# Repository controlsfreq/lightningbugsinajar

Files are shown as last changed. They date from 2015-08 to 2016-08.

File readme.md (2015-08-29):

# Readme #

The Lightning Bugs in a Jar (LBJ) application is used to control up to 8 LEDs and flash them randomly as if they were lightning bugs.

## Toolchain ##

* [WinAVR](http://sourceforge.net/projects/winavr/files/) - Compiler, linker, archiver, etc.
* [AvrDude](http://www.nongnu.org/avrdude/) - Programmer interface application.
* [LibUSB](http://sourceforge.net/projects/libusb-win32/) - USB driver for AvrDude which allows it to interface with the AVRISP mkII. Running `bin/inf-wizard.exe` will create a driver for a connected AVRISP mkII and install it.
* [Cygwin](https://www.cygwin.com) - Provides Make and a build environment.

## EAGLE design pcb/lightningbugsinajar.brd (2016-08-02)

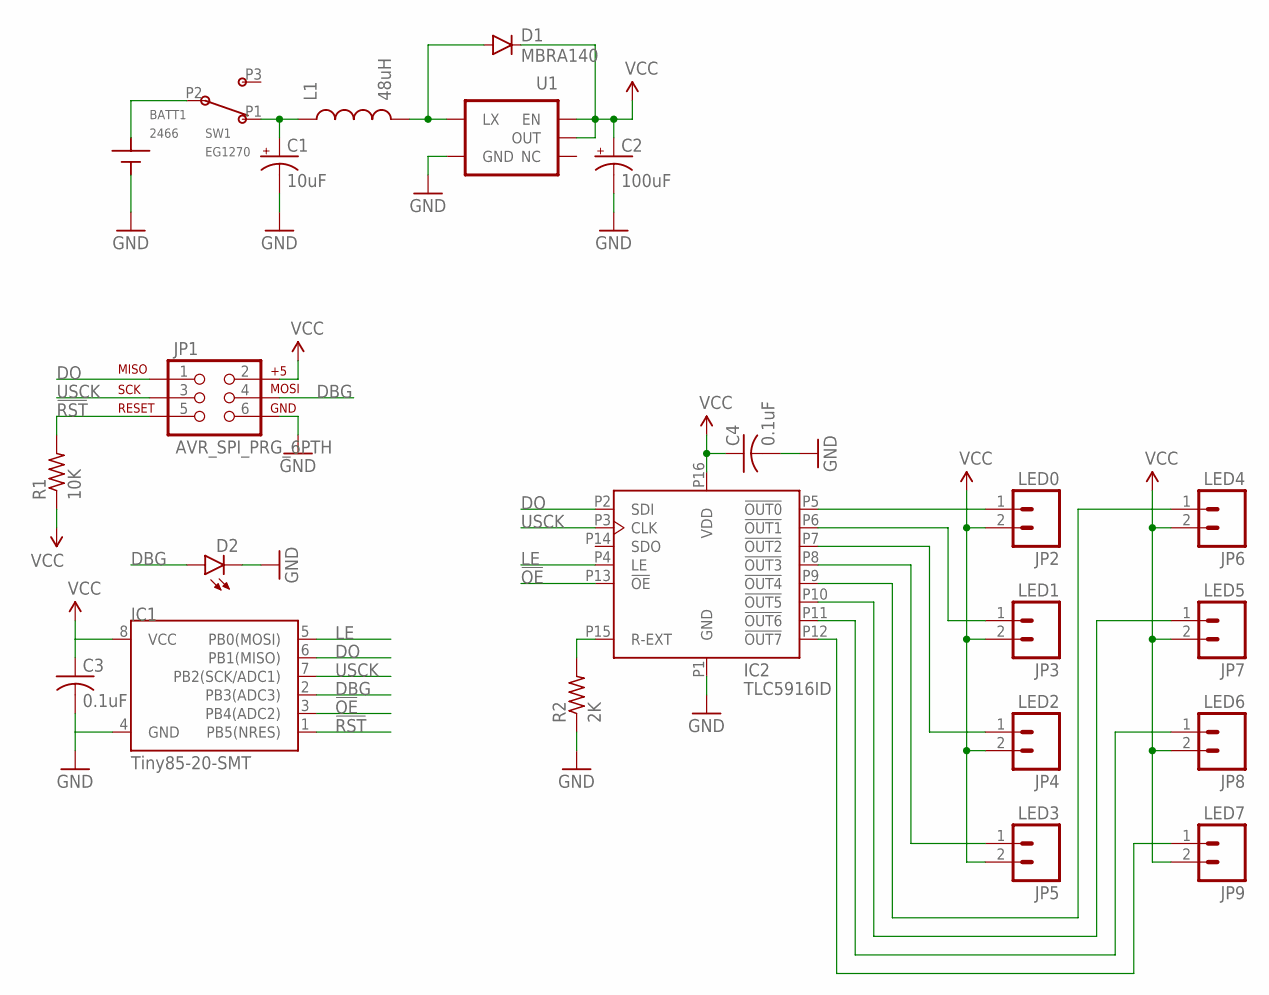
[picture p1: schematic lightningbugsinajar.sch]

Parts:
BATT1: 2466
C1: 10uF; EIA3528
C2: 100uF; EIA3528
C3, C4: 0.1uF; C0805
D1: MBRA140; SMA-DIODE
D2: LED3MM
IC1: Tiny85-20-SMT; SO08-EIAJ
IC2: TLC5916ID; SOIC-16
JP1: AVR_SPI_PRG_6PTH; 2X3
JP2: LED0; 1X02
JP3: LED1; 1X02
JP4: LED2; 1X02
JP5: LED3; 1X02
JP6: LED4; 1X02
JP7: LED5; 1X02
JP8: LED6; 1X02
JP9: LED7; 1X02
L1: 48uH; CR54
R1: 10K; R0805
R2: 2K; R0805
SW1: EG1270
U1: V_REG_NCP1400SOT23-5; SOT23-5

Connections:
3: SW1.P3 (3)
!OE: IC1.3 (PB4(ADC2)), IC2.P13 (!OE)
!RST: IC1.1 (PB5(NRES)), JP1.5, R1.2
DBG: D2.A, IC1.2 (PB3(ADC3)), JP1.4
DO: IC1.6 (PB1(MISO)), IC2.P2 (SDI), JP1.1
GND: BATT1.NEG, C1.C (-), C2.C (-), C3.2, C4.2, D2.K (C), IC1.4 (GND), IC2.P1 (GND), JP1.6, R2.1, U1.4 (GND)
LE: IC1.5 (PB0(MOSI)), IC2.P4 (LE)
unnamed: C1.A (+), L1.P$1 (1), SW1.P1 (1)
unnamed: D1.A, L1.P$2 (2), U1.5 (LX)
unnamed: IC2.P5 (!OUT0), JP2.1
unnamed: IC2.P15 (R-EXT), R2.2
unnamed: IC2.P6 (!OUT1), JP3.1
unnamed: IC2.P7 (!OUT2), JP4.1
unnamed: IC2.P8 (!OUT3), JP5.1
unnamed: IC2.P9 (!OUT4), JP6.1
unnamed: IC2.P10 (!OUT5), JP7.1
unnamed: BATT1.POS, SW1.P2 (COM)
unnamed: IC2.P11 (!OUT6), JP8.1
unnamed: IC2.P12 (!OUT7), JP9.1
USCK: IC1.7 (PB2(SCK/ADC1)), IC2.P3 (CLK), JP1.3
VCC: C2.A (+), C3.1, C4.1, D1.C, IC1.8 (VCC), IC2.P16 (VDD), JP1.2, JP2.2, JP3.2, JP4.2, JP5.2, JP6.2, JP7.2, JP8.2, JP9.2, R1.1, U1.1 (EN), U1.2 (OUT)

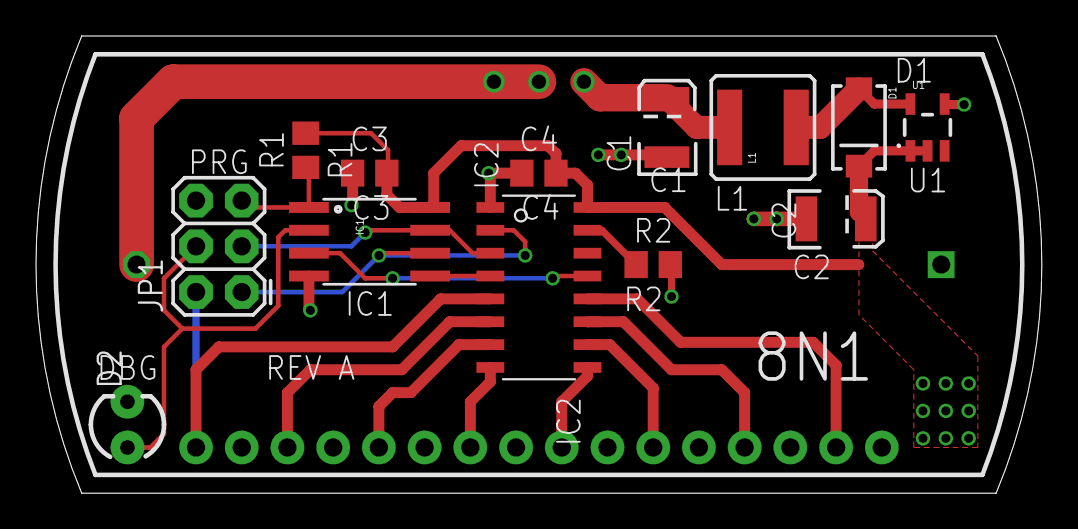
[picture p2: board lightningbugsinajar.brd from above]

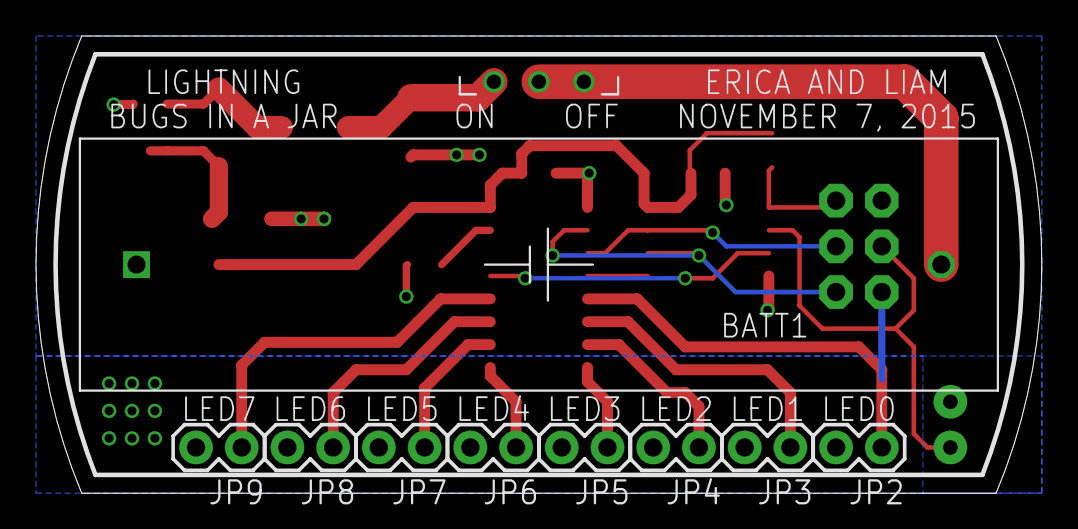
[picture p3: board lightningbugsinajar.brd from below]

Board: 2 copper layers, 55.9 x 25.4 mm, 23 parts (10 on the bottom side), 20 nets.

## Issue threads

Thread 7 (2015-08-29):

Create TLC591x driver

controlsfreq, 2015-08-29:
Create a TLC591x driver which allows control of an individual LED or all 8 at once. No error detection necessary, no special mode necessary, output enable should be made optional.

Closed 2015-08-30.

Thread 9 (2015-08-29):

Create a basic SPI driver

controlsfreq, 2015-08-29:
Create a basic SPI driver which allows setting baud rate (some set values) and reading and writing from/to the bus. Also, allows manual control of CS pin.

Closed 2015-08-30.

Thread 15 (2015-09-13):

Create AVR Timer1 driver

controlsfreq, 2015-09-13:
Create a timer1 driver for the AVR attiny. Timer must support interrupting at specified intervals.

Closed 2015-09-17.

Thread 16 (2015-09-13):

Add ISR for Timer1 which increments soft-PWM counter

controlsfreq, 2015-09-13:
Add an application level ISR which increments the soft-PWM counter.

controlsfreq, 2015-09-17:
This is already included in #17. No need to have a separate task for it.

Closed 2015-09-17.

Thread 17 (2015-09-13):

Write application layer soft-PWM module

controlsfreq, 2015-09-13:
Write a software PWM module at the application layer. This module must use the Timer1 driver to interrupt at a set time period and use a software counter to determine the correct output level of a single channel. This module must update the TLC5916 driver with the currently set PWM value whenever the channel value is changed (may be updated at each time step if necessary).

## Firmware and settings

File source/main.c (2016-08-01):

/**
 * @file   main.c
 * @brief  This file contains the main entry point to the LED Bugs In A Jar application.
 * @author Liam Bucci <liam.bucci@gmail.com>
 * @date   2015-08-23
 * @copyright
 * {
 *     Copyright 2015 Liam Bucci
 *
 *     Licensed under the Apache License, Version 2.0 (the "License");
 *     you may not use this file except in compliance with the License.
 *     You may obtain a copy of the License at
 *
 *         http://www.apache.org/licenses/LICENSE-2.0
 *
 *     Unless required by applicable law or agreed to in writing, software
 *     distributed under the License is distributed on an "AS IS" BASIS,
 *     WITHOUT WARRANTIES OR CONDITIONS OF ANY KIND, either express or implied.
 *     See the License for the specific language governing permissions and
 *     limitations under the License.
 * }
 */

#define F_CPU 1000000UL

#include <avr/io.h>
#include <avr/interrupt.h>
#include <util/delay.h>

#include "pin.h"
#include "spi.h"
#include "tlc591x.h"
#include "controller.h"
#include "timer.h"

volatile uint8_t g_timer_counter = 0;

pin_t debug_pin = {
    PIN_BANK_B,
    PIN_NUM_3,
    false
};

int main( int argc, char *argv[] )
{
	//char major_version = LBJ_MAJOR_VERSION;
	//char minor_version = LBJ_MINOR_VERSION;
	//char patch_version = LBJ_PATCH_VERSION;

    timer_t timer1 = {
        TIMER_NUM_1,
        TIMER_PRE_8,
        true
    };

    spi_t spi = {
        SPI_BAUD_1M,
        {
            PIN_BANK_B,
            PIN_NUM_3,
            true
        }, // SPI CS
        {
            PIN_BANK_B,
            PIN_NUM_1,
            false
        }, // SPI MOSI
        {
            PIN_BANK_B,
            PIN_NUM_0,
            false
        }, // SPI MISO
        {
            PIN_BANK_B,
            PIN_NUM_2,
            false
        } // SPI SCLK
    };

    tlc591x_t tlc = {
        spi,
        { PIN_BANK_B, PIN_NUM_0, true },
        { PIN_BANK_B, PIN_NUM_4, false }
    };

    (void)timer_init( &timer1 );
    (void)timer_set_compare( &timer1, 125 );
    (void)tlc591x_init( &tlc );
    (void)tlc591x_enable_output( &tlc );

    sei();

    (void)timer_enable_int( &timer1 );
    (void)timer_start( &timer1 );

    (void)controller_init( &tlc );
    (void)controller_loop();

	return 0;
}



ISR(INT0_vect)
{
    (void)pin_assert( &debug_pin );
    while(1); /* Trap */
}

ISR(PCINT0_vect)
{
    (void)pin_assert( &debug_pin );
    while(1); /* Trap */
}

ISR(TIM1_OVF_vect)
{
    (void)pin_assert( &debug_pin );
    while(1); /* Trap */
}

ISR(TIM0_OVF_vect)
{
    (void)pin_assert( &debug_pin );
    while(1); /* Trap */
}

ISR(EE_RDY_vect)
{
    (void)pin_assert( &debug_pin );
    while(1); /* Trap */
}

ISR(ANA_COMP_vect)
{
    (void)pin_assert( &debug_pin );
    while(1); /* Trap */
}

ISR(ADC_vect)
{
    (void)pin_assert( &debug_pin );
    while(1); /* Trap */
}

ISR(TIM1_COMPB_vect)
{
    (void)pin_assert( &debug_pin );
    while(1); /* Trap */
}

ISR(TIM0_COMPA_vect)
{
    (void)pin_assert( &debug_pin );
    while(1); /* Trap */
}

ISR(TIM0_COMPB_vect)
{
    (void)pin_assert( &debug_pin );
    while(1); /* Trap */
}

ISR(WDT_vect)
{
    (void)pin_assert( &debug_pin );
    while(1); /* Trap */
}

ISR(USI_START_vect)
{
    (void)pin_assert( &debug_pin );
    while(1); /* Trap */
}

ISR(USI_OVF_vect)
{
    (void)pin_assert( &debug_pin );
    while(1); /* Trap */
}

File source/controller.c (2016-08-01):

/**
 * @file   controller.c
 * @brief  This file contains the controller for 2, 4, or 8 LEDs.
 * @author Liam Bucci <liam.bucci@gmail.com>
 * @date   2015-08-23
 * @copyright
 * {
 *     Copyright 2015 Liam Bucci
 *
 *     Licensed under the Apache License, Version 2.0 (the "License");
 *     you may not use this file except in compliance with the License.
 *     You may obtain a copy of the License at
 *
 *         http://www.apache.org/licenses/LICENSE-2.0
 *
 *     Unless required by applicable law or agreed to in writing, software
 *     distributed under the License is distributed on an "AS IS" BASIS,
 *     WITHOUT WARRANTIES OR CONDITIONS OF ANY KIND, either express or implied.
 *     See the License for the specific language governing permissions and
 *     limitations under the License.
 * }
 */

#include <avr/io.h>
#include <avr/interrupt.h>
#include "tlc591x.h"
#include "pin.h"
#include "ufprng.h"
#include "controller.h"

#define PWM_CHANNELS     8U
#define PWM_RESOLUTION   128U    ///< Must be a power of 2
#define WAVEFORM_UPDATE_COUNT 2U ///< Must be a power of 2
#define WAVEFORM_LENGTH  64U     ///< Must be a power of 2
#define WAVEFORM_ACTIVE_MASK 0x1FU
#define PRNG_UPDATE_COUNT 64U    ///< Must be a power of 2

#ifndef PRNG_SEED
#define PRNG_SEED 1
#endif

/*
 * Use a software counter to implement PWM. Every Timer1 overflow the PWM counter will increment
 * and the controller_loop will update the output values of all PWM channels according to their
 * current duty cycle values.
 *
 * The duty cycle values are taken from the waveform values. The current index of the waveform is
 * stored in g_waveform_index for each LED channel. The waveform index for each channel is only
 * incremented passed zero if the channel is marked active in g_waveform_active. When a channel is
 * marked active it increments it's waveform index every WAVEFORM_UPDATE_COUNT PWM periods.
 *
 * PWM bit = 125us
 * PWM period = 128 * 125us = 16ms
 * Waveform update = 2 * 16ms = 32ms
 * Waveform rollover = 64 * 32ms = 2.048s
 */
static volatile uint8_t g_pwm_dutycycle_counter = 0;
static volatile bool g_pwm_update_flag = false;
static volatile uint8_t g_waveform_update_counter = 0;
static volatile uint8_t g_waveform_index[PWM_CHANNELS] = { 0 };
static volatile bool g_waveform_active[PWM_CHANNELS] = { false, false, false, false, false, false, false, false };
static const uint8_t WAVEFORM_VALUES[WAVEFORM_LENGTH] = {   0,   2,   4,   8,  14,  22,  30,  40,
                                                           50,  60,  72,  82,  94, 102, 110, 118,
                                                          122, 126, 128, 126, 126, 122, 118, 114,
                                                          108, 102,  96,  88,  82,  74,  68,  60,
                                                           54,  48,  42,  38,  34,  28,  26,  22,
                                                           18,  16,  14,  12,  10,   8,   6,   5,
                                                            4,   3,   2,   2,   1,   0,   0,   0,
                                                            0,   0,   0,   0,   0,   0,   0,   0 };
static uint8_t g_prng_update_counter = 0;
static uint8_t g_output_value = 0x00U;
static tlc591x_t * g_ptlc;
static bool g_run = true;
static ufprng_t g_prng;

pin_t debug_pin_test = {
    PIN_BANK_B,
    PIN_NUM_3,
    false
};

bool controller_init( tlc591x_t * const tlc )
{
    g_ptlc = tlc;

    // Seed prng
    ufprng_seed( &g_prng, PRNG_SEED );

    return true;
}

bool controller_loop( void )
{
    bool error_code = false;
    uint8_t local_pwm_dutycycle_counter = 0;
    uint8_t i = 0;

    while( g_run )
    {
        // Busy wait until next pwm update
        while( g_pwm_update_flag == false );

        // Get a local copy of the PWM duty cycle counter in case we don't finish before the next interrupt
        local_pwm_dutycycle_counter = g_pwm_dutycycle_counter;

        // Mark PWM as not ready to update as soon as possible so we don't miss a count
        g_pwm_update_flag = false;

        // Debug
        pin_toggle( &debug_pin_test );

        // Update waveform and prng update counters
        if( local_pwm_dutycycle_counter == 0 )
        {
            g_waveform_update_counter++;
            g_waveform_update_counter &= WAVEFORM_UPDATE_COUNT-1;

            g_prng_update_counter++;
            g_prng_update_counter &= PRNG_UPDATE_COUNT-1;
        }

        // Update the active waveforms according to prng
        if( (local_pwm_dutycycle_counter == 0) &&
            (g_prng_update_counter == 0)       )
        {
            uint8_t randnum = ufprng_rand( &g_prng );

            for( i = 0; i < PWM_CHANNELS; i++ )
            {
                if( (randnum & WAVEFORM_ACTIVE_MASK) == i )
                {
                    g_waveform_active[i] = true;
                }
            }
        }

        // Update the relevant waveform indexes
        if( (local_pwm_dutycycle_counter == 0) &&
            (g_waveform_update_counter == 0)   )
        {
            for( i = 0; i < PWM_CHANNELS; i++ )
            {
                if( g_waveform_active[i] == true )
                {
                    g_waveform_index[i]++;
                    g_waveform_index[i] &= WAVEFORM_LENGTH-1;

                    // Must disable waveform if we wrap here
                    if( g_waveform_index[i] == 0 )
                    {
                        g_waveform_active[i] = false;
                    }
                }
            }
        }

        // Update PWM values according to waveform values
        for( i = 0; i < PWM_CHANNELS; i++ )
        {
            g_output_value = (local_pwm_dutycycle_counter >= WAVEFORM_VALUES[g_waveform_index[i]]) ?
                             g_output_value & ~(1<<i) :
                             g_output_value | (1<<i);
        }

        // Update LED display
        tlc591x_write_values( g_ptlc, g_output_value );

        // Debug
        pin_toggle( &debug_pin_test );
    }

    return error_code;
}

ISR(TIM1_COMPA_vect)
{
    // Increment PWM counter
    g_pwm_dutycycle_counter++;

    // Rollover counter on last valid duty cycle
    g_pwm_dutycycle_counter &= PWM_RESOLUTION-1;

    // Mark PWM values as ready to update
    g_pwm_update_flag = true;
}

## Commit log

2015-08-29 Hello World Application
    * Changed Makefile to build embedded project. Builds all objects, then
    an elf file, then converts it to an Intel hex.
    * Changed main to flash an LED connected on PB3.
    * Added a readme.md which describes the required toolchain (including
    usb driver for the AVRISP mkII).
2015-08-30 Pin Driver
    * Added pin driver. AVR implementation only supports bank B. Tested
    toggle, assert, and deassert functions.
2015-08-30 SPI Driver
    * Added an SPI driver. Sends SPI data in mode CPOL=1, CPHA=1 (compatible
    with the TLC591x).
    * Tested by sending data and reading with a Saleae Logic analyzer.
2015-08-30 TLC591x Driver and bug fixes
    * Added a TLC591x driver which uses the SPI driver to send output values
    to the TLC591x chip. Controls the LE and !OE lines as necessary.
    * Bug fixes in the SPI driver:
    * Return value wasn't correct.
    * Initial register value wasn't correct.
    [main.c]
2015-09-17 Timer1, Linker Script, Fuse Bits
    * Added general Timer interface.
    * Added AVR timer1 implementation.
    * Added linker script with attiny85 memory settings (avr-gcc uses a
    generic script with inflated memory regions).
    * Added command line options to program fuse bits from Makefile.
2016-08-02 Adds Eagle CAD files
    [lightningbugsinajar.brd, lightningbugsinajar.sch]

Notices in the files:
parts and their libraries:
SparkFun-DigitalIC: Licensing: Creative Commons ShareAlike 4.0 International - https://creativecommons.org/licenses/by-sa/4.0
